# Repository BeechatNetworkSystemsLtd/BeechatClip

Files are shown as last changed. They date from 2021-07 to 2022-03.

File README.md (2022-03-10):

# Beechat Clip
## _The clip-on hardware for the Beechat Network_

BNSLTD

General
-------------------

This product is a plug-and-play RF module that operates with the Digi XBee SMT line. This unit works with all XBee SMT Pad modules, standard and Pro version. Design consists of an XBee® SX 868 module and USB-to-UART converter that allows users to simply plug the module into their smartphone over USB-C cable.

Additional on-board LED indication for TX/RX data, RSSI level and power (5V) in FT231XQ-R version. Reset tactile button allows rebooting the RF module when needed.  

Repository Contents
-------------------

* **/Hardware** - All Eagle design files (.brd, .sch)
* **/Production** - Test bed files and production panel files

Images
-------------------
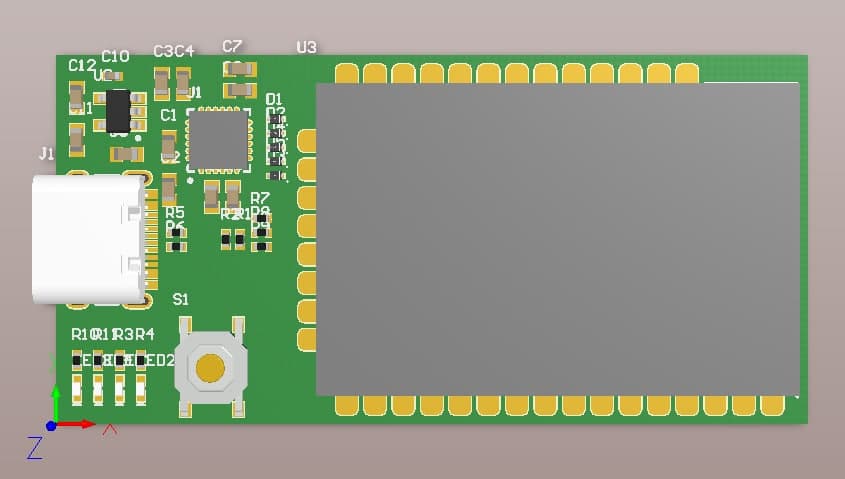
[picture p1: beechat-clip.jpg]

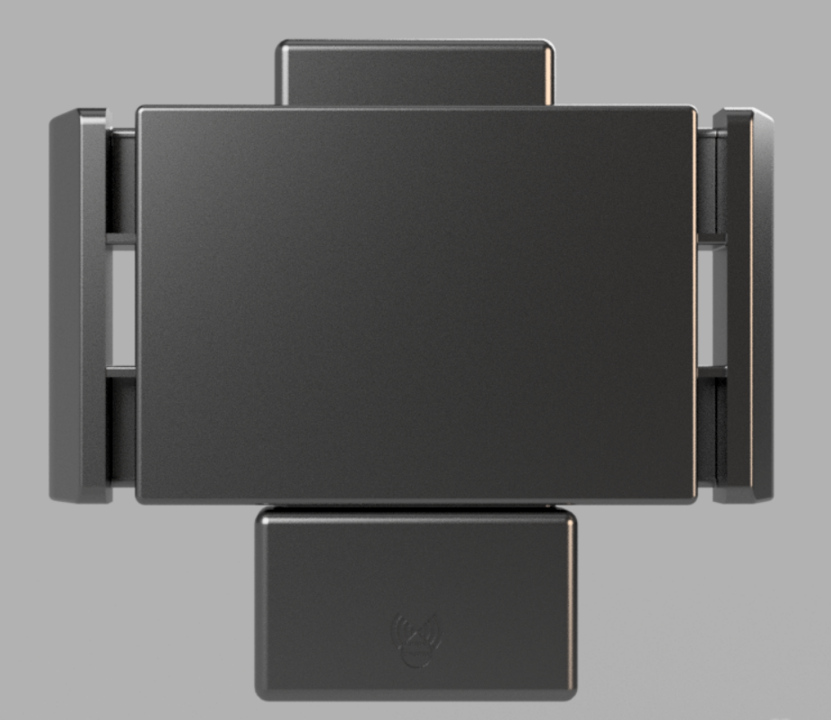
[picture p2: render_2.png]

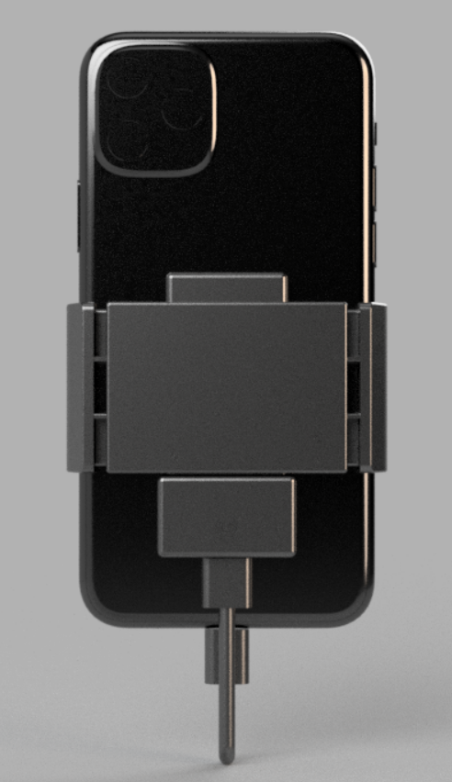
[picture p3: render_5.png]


Features
-------------------

* **Dimensions:** 26 x 53 mm
* **USB - UART bridge:** FT231XQ-R or XR21V1410
* **RF module:** XB8X-DMUS-001 or XBP9X-DMUS-001 or another XBee SX module
* **Input voltage:** 5V (USB)
* **Logic of UART signal:** 3.3V

Repository Contents
-------------------

/FT231XQ-R version:
* /Step 1 - PCB Manufacturing  (Gerber files, NC Drill, PCB specs)
* /Step 2 - Board Assembly (Pick & Place, Assembly drawing, 3DPDF, BOM)
* /Step 3 - 3D (3DPDF, STEP 3D)
* /Step 4 - Schematic (PDF schematic)
* /Step 5 - Source Files (source design in Altium Designer)

/XR21V1410 version:
* /Step 1 - PCB Manufacturing  (Gerber files, NC Drill, PCB specs)
* /Step 2 - Board Assembly (Pick & Place, Assembly drawing, 3DPDF, BOM)
* /Step 3 - 3D (3DPDF, STEP 3D)
* /Step 4 - Schematic (PDF schematic)
* /Step 5 - Source Files (source design in Altium Designer)

Product Versions
-------------------

REV1.0 - first design revision

License Information
-------------------
The hardware is released under [Creative Commons ShareAlike 4.0 International](https://creativecommons.org/licenses/by-sa/4.0/).
All other trademarks, service marks and company names are the property of their respective owners.

Distributed as-is; no warranty is given.

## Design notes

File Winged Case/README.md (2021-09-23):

# Beechat Clip Enclosure

BNSLTD

General
-------------------
This folder contains the files for the enclosure of the Beechat Clip.  

Bill of Materials
-------------------
 Sr No | Part name | Quantity | Material | Link/description |
| ------ | ------ | ------ | ------ | ------ |
|1 | Case top | 1 | PC
|2 | Case middle | 1 | PC
|3 | Case left | 1 | PC
|4 | Case right | 1 | PC
|5 | Spring | 2 | Spring steel | Wire dia- 0.5mm,  free length -11 mm, OD- 5mm, number of active coils =5
|6 | M1.6 screw 4mm | 2 |
|7 | M1.6 screw 6mm | 2 | 
|8 | Type C cable | 1 | 

REV1.0 - first design revision

License Information
-------------------
The hardware is released under [Creative Commons ShareAlike 4.0 International](https://creativecommons.org/licenses/by-sa/4.0/).

Distributed as-is; no warranty is given.

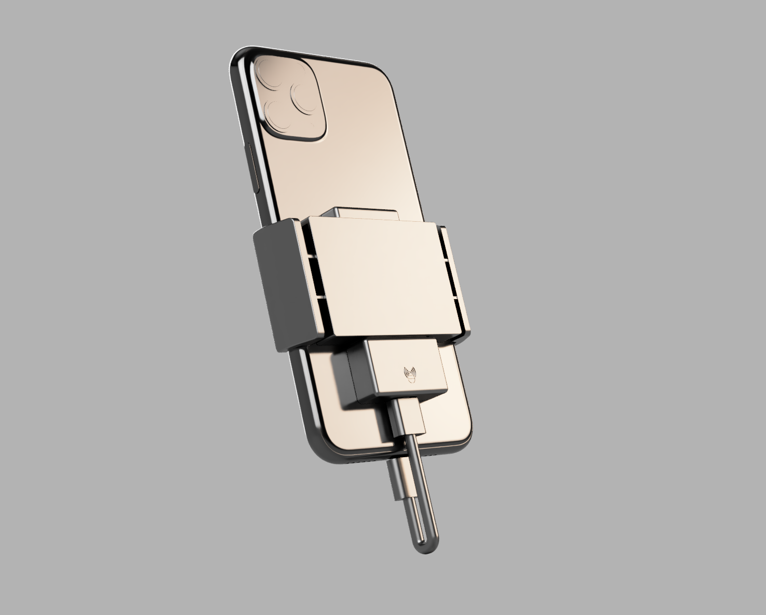
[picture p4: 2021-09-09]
render_1.PNG

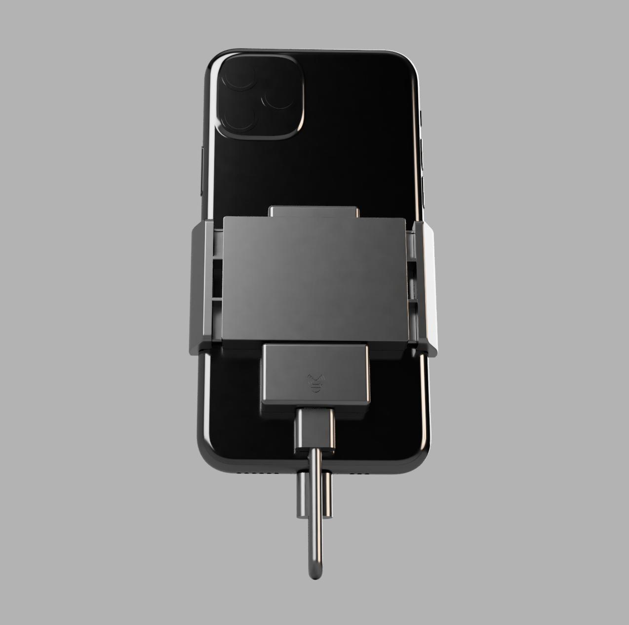
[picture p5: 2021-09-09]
Winged Case/Beechat clip render 4.PNG

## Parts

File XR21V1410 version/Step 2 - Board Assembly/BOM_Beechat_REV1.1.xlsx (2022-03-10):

 |  |  | Beechat, REV1.1 BOM file
 |  |  |  | Status: Checked
Disignator | Quantity | Value | Manufacturer Part Number | Description | Footprint | Supplier code
C1, C9 | 2 | 4.7uF | LMK107BJ475KA-T | CAP CER 4.7UF 10V X5R 0603 | CAP0603 | C1705
C2, C4, C6, C10 | 4 | 100nF | GRM155R71H104KE14D | CAP CER 0.1UF 50V X7R 0402 | CAP0402 | C105883
C3, C5, C7 | 3 | 10uF | LMK107BJ106MALTD | CAP CER 10UF 10V X5R 0603 | CAP0603 | C85713
C8 | 1 | 10nF | GCM155R71H103KA55D | CAP CER 10000PF 50V X7R 0402 | CAP0402 | C91601
D1, D2, D3, D4, D5 | 5 | - | ESD9B5.0ST5G | TVS DIODE 5V SOD923 | SOD-923 | C434878
J1 | 1 | - | USB4105-GF-A | USB SHIELDED I/O RECP TYPE C | SMD | C319148
LED1 | 1 | Green | APHHS1005CGCK | LED GREEN CLEAR CHIP SMD | LED0402 | C434446
LED2 | 1 | Red | APHHS1005LSECK/J3-PF | LED RED CLEAR 2SMD | LED0402 | C71911
R1, R2 | 2 | 22R | RC0402FR-0722RL | RES SMD 22 OHM 1% 1/16W 0402 | RES0402 | C114765
R3, R4 | 2 | 5.1K | RC0402FR-075K1L | RES SMD 5.1K OHM 1% 1/16W 0402 | RES0402 | C105872
R5, R6 | 2 | 4.7K | RC0402FR-074K7L | RES SMD 4.7K OHM 1% 1/16W 0402 | RES0402 | C105871
R7 | 1 | 330R | RC0402FR-07330RL | RES SMD 330 OHM 1% 1/16W 0402 | RES0402 | C105875
R8 | 1 | 1K | RT0402FRE071KL | RES SMD 1K OHM 1% 1/16W 0402 | RES0402 | C106235
S1 | 1 | - | 8-1437565-1 | SWITCH TACTILE SPST-NO 0.02A 15V | SMD | C318884
U1 | 1 | - | XR21V1410IL16-F | IC UART FIFO USB SGL 16QFN | QFN-16 | 1016-1300-ND
U2 | 1 | 3.3V | LDS3985M33R | IC REG LINEAR 3.3V 300MA SOT23-5 | SOT23-5 | C167141
U3 | 1 | - | XBP9X-DMUS-001 | RX TXRX MOD ISM < 1GHZ U.FL SMD | SMD | XBP9X-DMUS-001
TH = Through Hole
NF = Not fitted

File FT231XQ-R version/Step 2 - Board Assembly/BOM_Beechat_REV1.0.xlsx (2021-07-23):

 |  |  | Beechat, REV1.0 BOM file
 |  |  |  | Status: Checked
Disignator | Quantity | Value | Manufacturer Part Number | Description | Footprint | Note | PCBGOGO Supplier Alternative (LCSC)
C1, C7, C9 | 3 | 10uF | LMK107BJ106MALTD | CAP CER 10UF 10V X5R 0603 | CAP0603 | Can be replaced with alternative | C85713
C2, C8 | 2 | 47pF | C0402C470K5GACTU | CAP CER 47PF 50V C0G/NP0 0402 | CAP0402 | Can be replaced with alternative | C60137
C3, C11 | 2 | 4.7uF | LMK107BJ475KA-T | CAP CER 4.7UF 10V X5R 0603 | CAP0603 | Can be replaced with alternative | C1705
C4, C5, C6, C12, C13, C14 | 6 | 100nF | GRM155R71H104KE14D | CAP CER 0.1UF 50V X7R 0402 | CAP0402 | Can be replaced with alternative | C105883
C10 | 1 | 10nF | GCM155R71H103KA55D | CAP CER 10000PF 50V X7R 0402 | CAP0402 | Can be replaced with alternative | NOT FITTED
D1, D2, D3, D4, D5 | 5 | 5V | ESD9B5.0ST5G | TVS DIODE 5V SOD923 | SOD-923 | Can be replaced with alternative | C434878
J1 | 1 | - | USB4105-GF-A | USB SHIELDED I/O RECP TYPE C | TH | Can be replaced with alternative | C319148
LED1, LED3 | 2 | Green | APHHS1005CGCK | LED GREEN CLEAR CHIP SMD | LED0402 | Can be replaced with alternative | C434446
LED2, LED4 | 2 | Red | APHHS1005LSECK/J3-PF | LED RED CLEAR 2SMD | LED0402 | Can be replaced with alternative | C71911
R3, R4, R11 | 3 | 1K | RT0402FRE071KL | RES SMD 1K OHM 1% 1/16W 0402 | RES0402 | Can be replaced with alternative | C106235
R5, R6 | 2 | 22R | RC0402FR-0722RL | RES SMD 22 OHM 1% 1/16W 0402 | RES0402 | Can be replaced with alternative | C114765
R8, R9 | 2 | 5.1K | RC0402FR-075K1L | RES SMD 5.1K OHM 1% 1/16W 0402 | RES0402 | Can be replaced with alternative | C105872
R10 | 1 | 330R | RC0402FR-07330RL | RES SMD 330 OHM 1% 1/16W 0402 | RES0402 | Can be replaced with alternative | C105875
S1 | 1 | - | 8-1437565-1 | SWITCH TACTILE SPST-NO 0.02A 15V | SMD | Can be replaced with alternative | C318884
U1 | 1 | - | FT231XQ | IC USB SERIAL FULL UART 20QFN | QFN-20
U2 | 1 | 3.3V | LDS3985M33R | IC REG LINEAR 3.3V 300MA SOT23-5 | SOT23-5 | Can be replaced with alternative | C167141
U3 | 1 | - | XB8X-DMUS-001 | RX TXRX MOD ISM < 1GHZ U.FL SMD | SMD
TH = Through Hole
NF = Not fitted

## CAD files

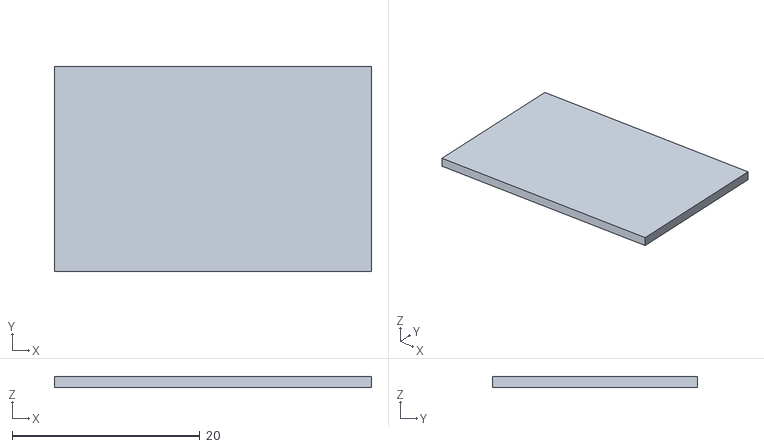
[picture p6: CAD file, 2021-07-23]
FT231XQ-R version/Step 3 - 3D/Beechat_PCB_REV1.0.stl
33.8 x 21.9 x 1.20

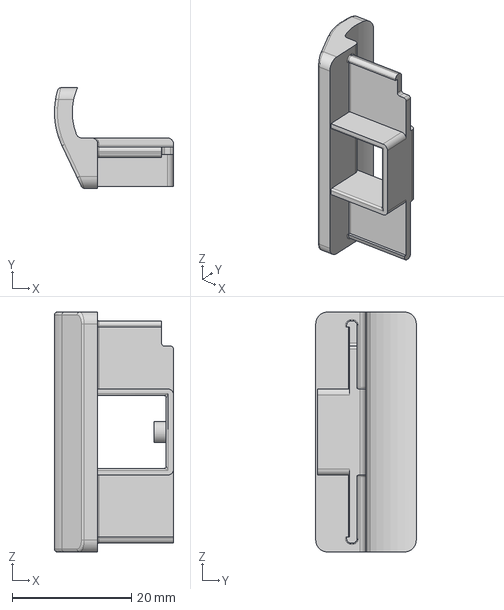
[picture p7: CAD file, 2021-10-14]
Step 6 - Enclosure case/parts/Case_right.step
20.0 x 16.9 x 40.3 mm

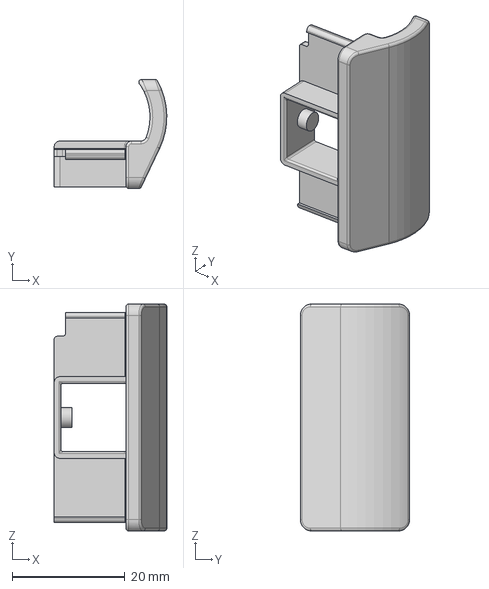
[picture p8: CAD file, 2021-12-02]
Winged Case/parts/Arm Model B .25cm/Case_Left-0.25CM.step
20.0 x 19.4 x 40.3 mm

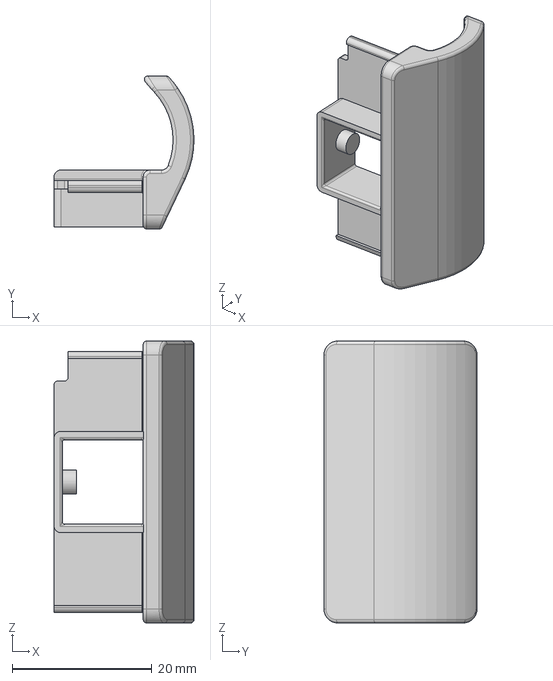
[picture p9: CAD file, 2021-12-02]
Winged Case/parts/Arm Model C .5cm/Case_Left-0.5CM.step
20.0 x 21.9 x 40.3 mm

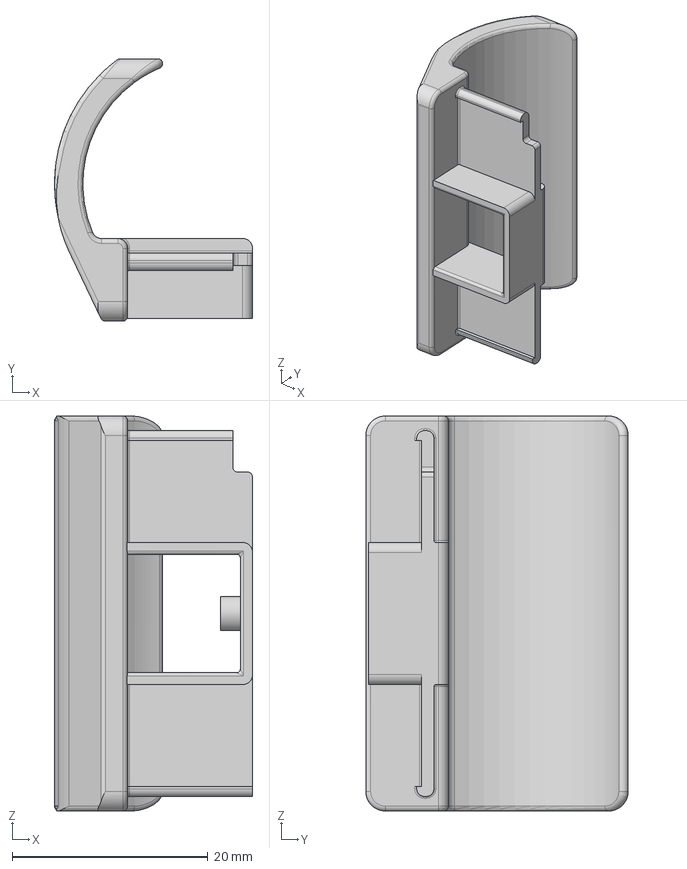
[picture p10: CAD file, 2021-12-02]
Winged Case/parts/Arm Model D 1cm/Case_Right-1CM.step
20.2 x 26.8 x 40.3 mm

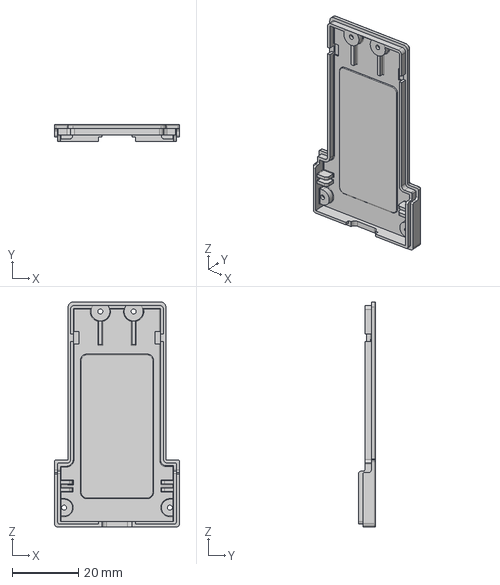
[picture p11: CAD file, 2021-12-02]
Winged Case/parts/Case_bottom.step
37.7 x 5.14 x 67.7 mm

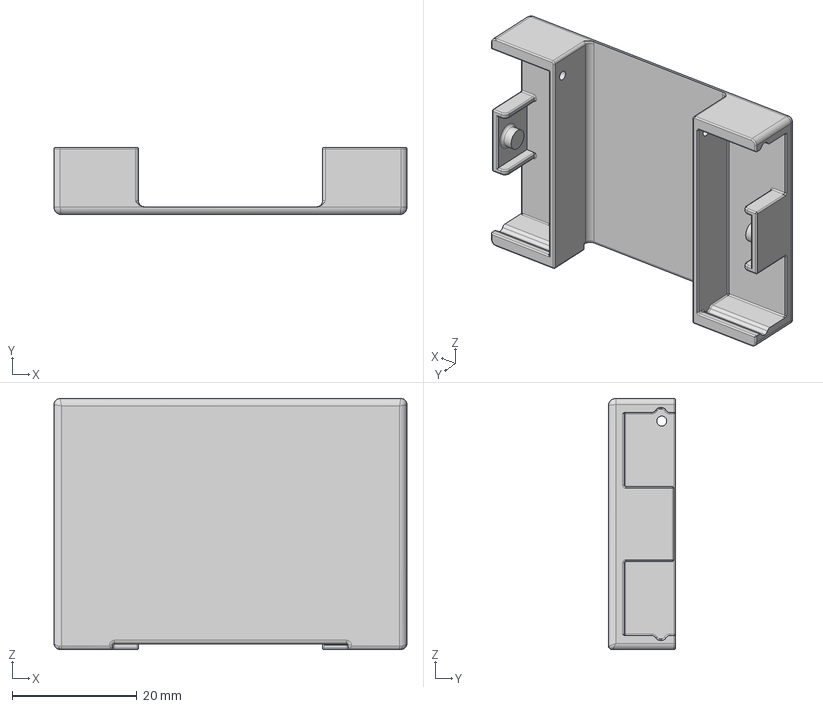
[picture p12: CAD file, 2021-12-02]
Winged Case/parts/Case_middle.step
56.7 x 10.8 x 40.3 mm

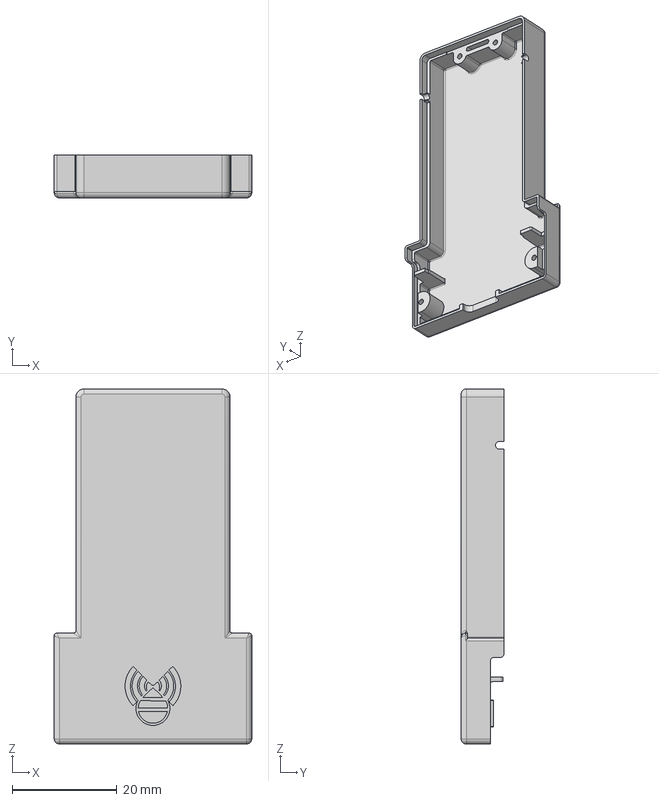
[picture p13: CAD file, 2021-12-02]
Winged Case/parts/Case_top.step
37.7 x 8.18 x 67.7 mm

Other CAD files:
Winged Case/parts/Arm Model A 0mm/Case_Right-0CM.step
Step 6 - Enclosure case/parts/Case_left.step
Winged Case/parts/Arm Model A 0mm/Case_Left-0CM.step
Winged Case/parts/Arm Model B .25cm/Case_Right-0.25CM.step
Winged Case/parts/Arm Model C .5cm/Case_Right-0.5CM.step
Winged Case/parts/Arm Model D 1cm/Case_Left-1CM.step

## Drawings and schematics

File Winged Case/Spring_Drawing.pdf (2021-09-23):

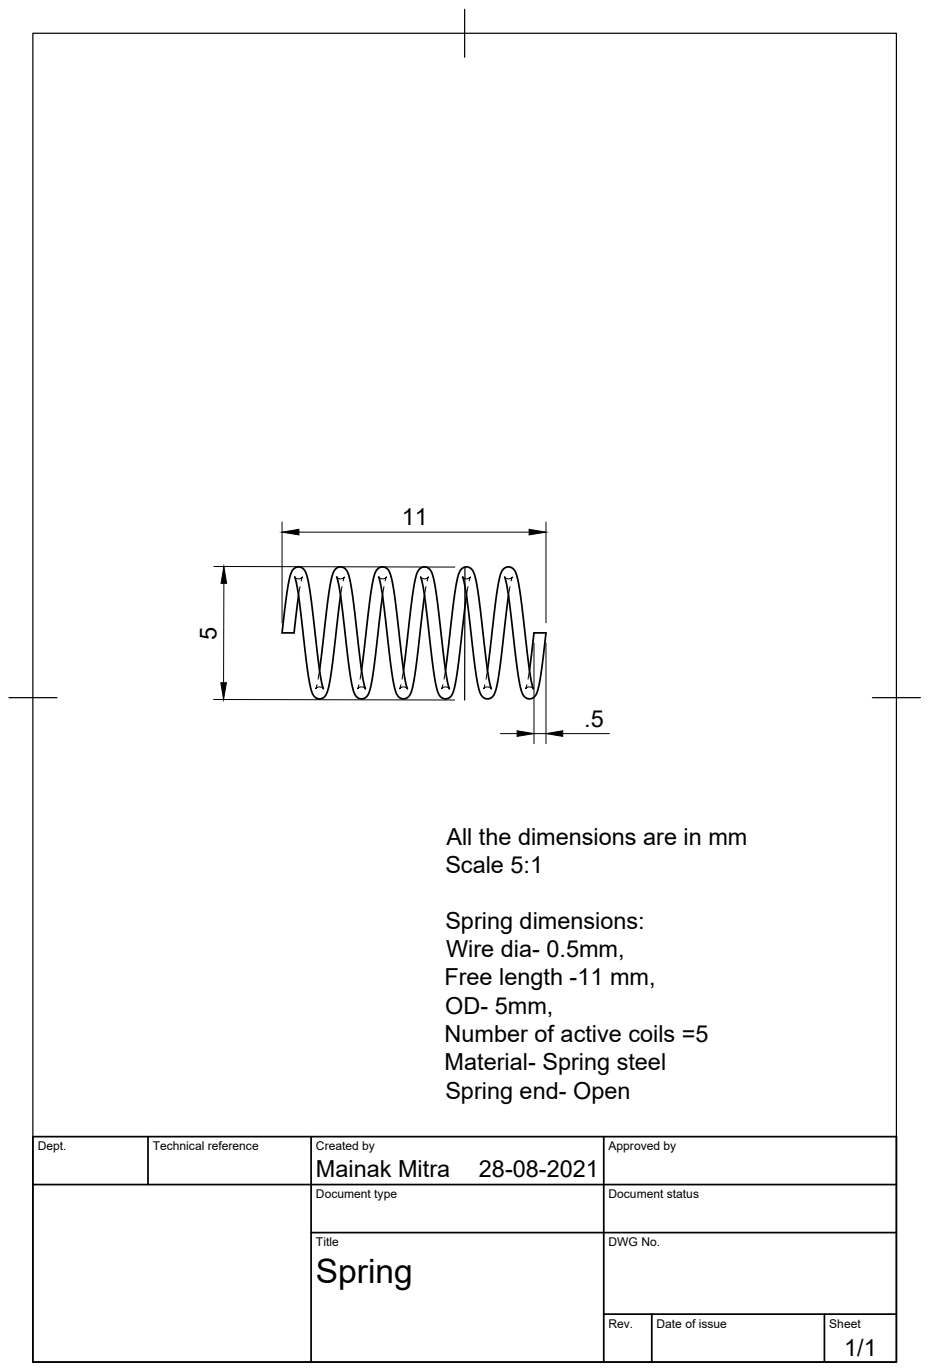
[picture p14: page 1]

All the dimensions are in mm
Scale 5:1

Spring dimensions:
Wire dia- 0.5mm,
Free length -11 mm,
Number of active coils =5
Material- Spring steel
Spring end- Open

Dept. | Technical reference | Created by Mainak Mitra 28-08-2021 | Approved by

Document type | Document status

Title Spring | DWG No.

Rev. | Date of issue | Sheet 1/1

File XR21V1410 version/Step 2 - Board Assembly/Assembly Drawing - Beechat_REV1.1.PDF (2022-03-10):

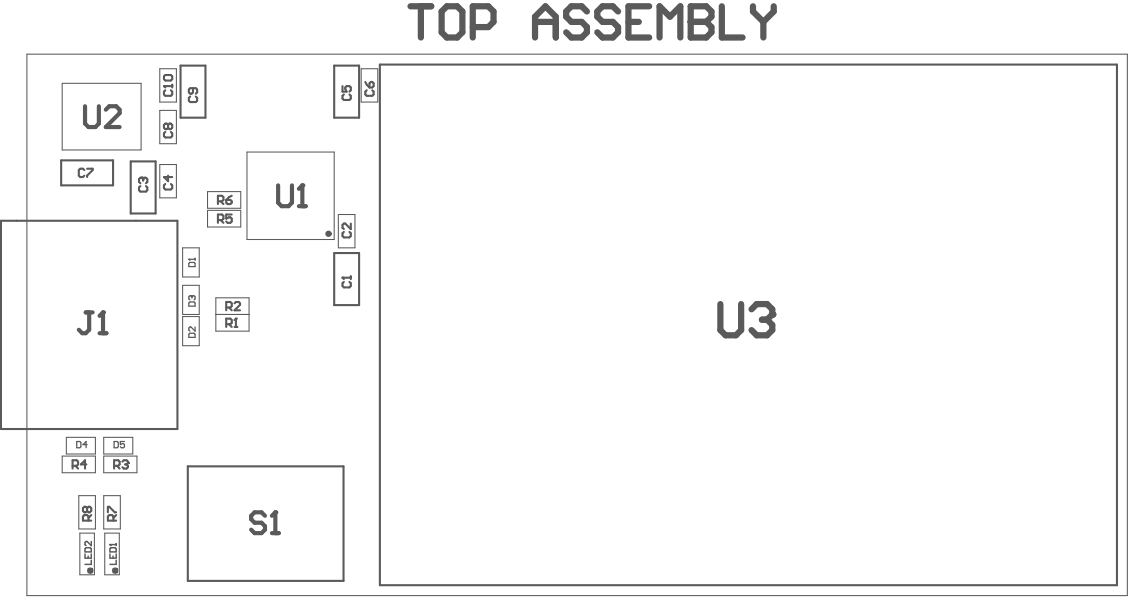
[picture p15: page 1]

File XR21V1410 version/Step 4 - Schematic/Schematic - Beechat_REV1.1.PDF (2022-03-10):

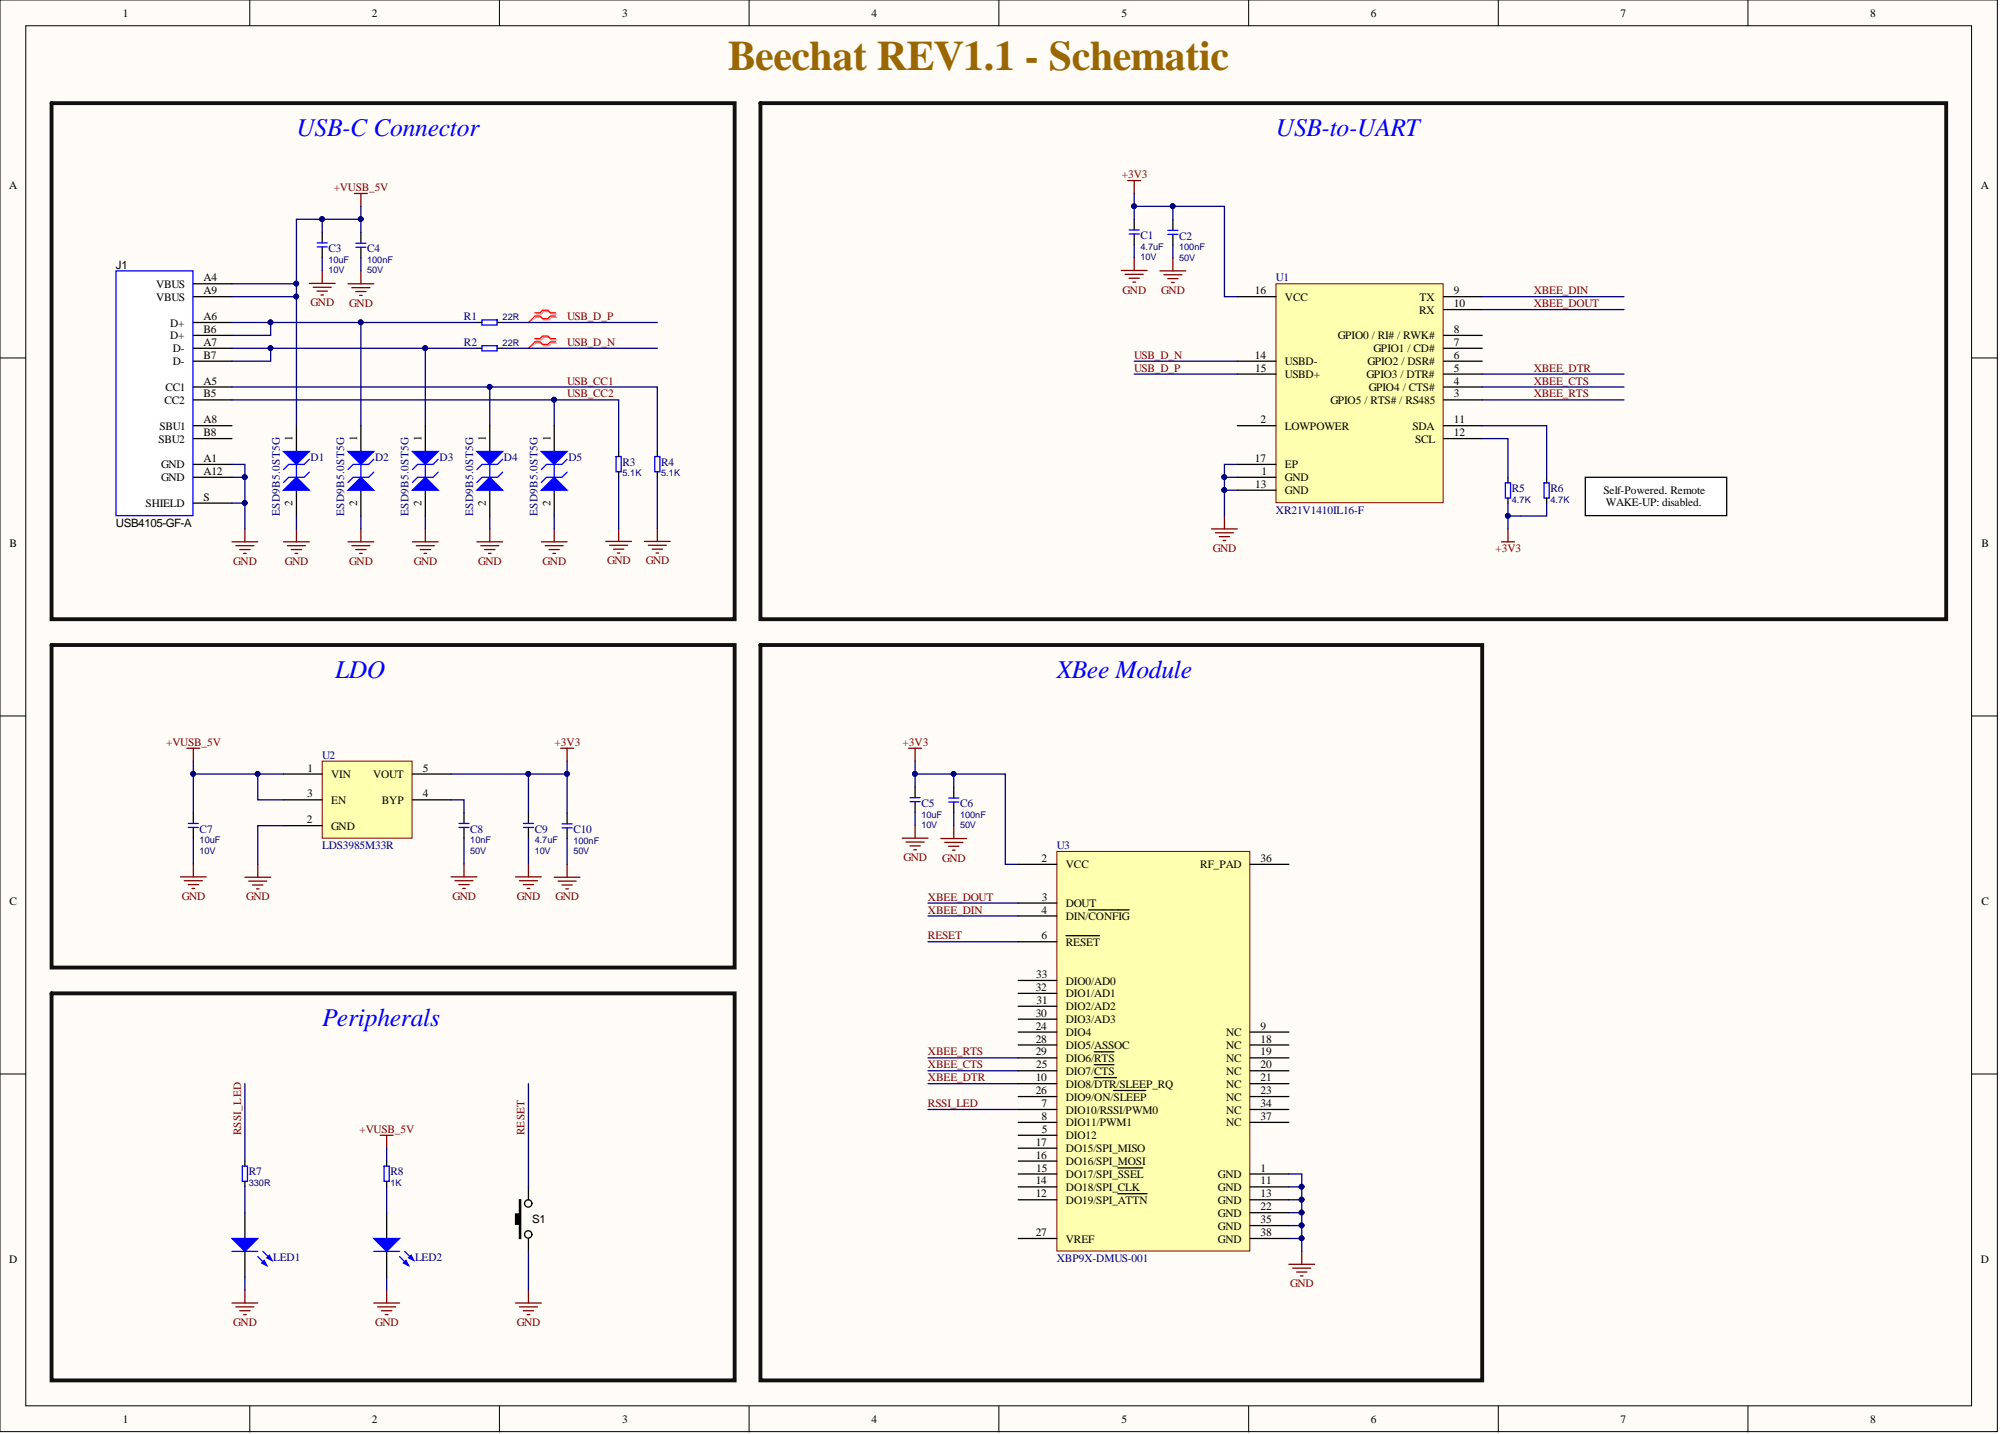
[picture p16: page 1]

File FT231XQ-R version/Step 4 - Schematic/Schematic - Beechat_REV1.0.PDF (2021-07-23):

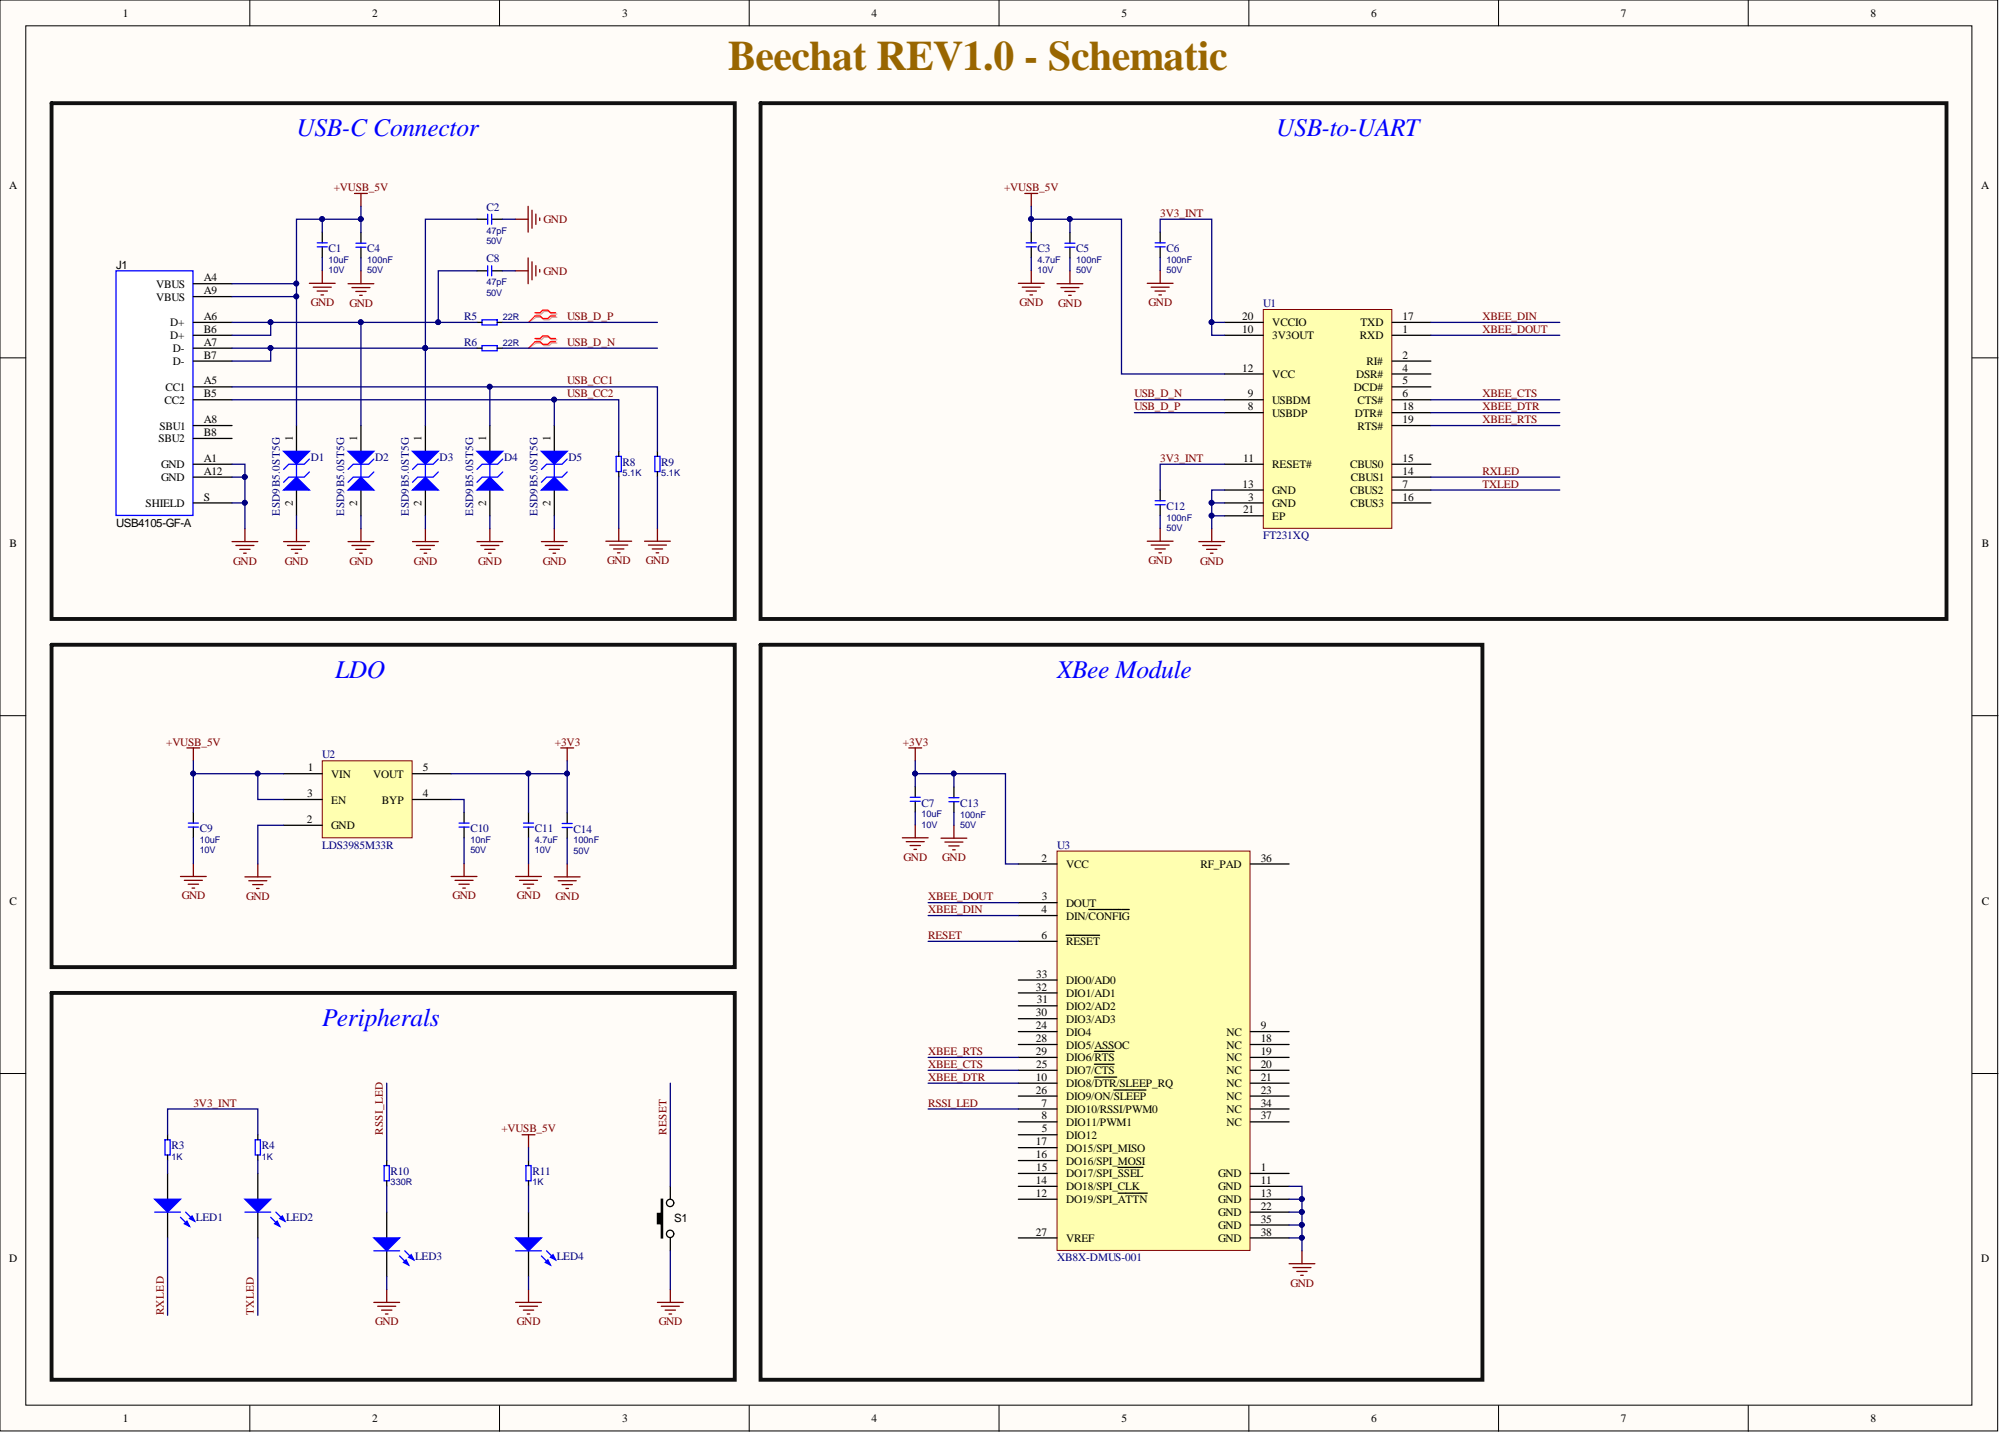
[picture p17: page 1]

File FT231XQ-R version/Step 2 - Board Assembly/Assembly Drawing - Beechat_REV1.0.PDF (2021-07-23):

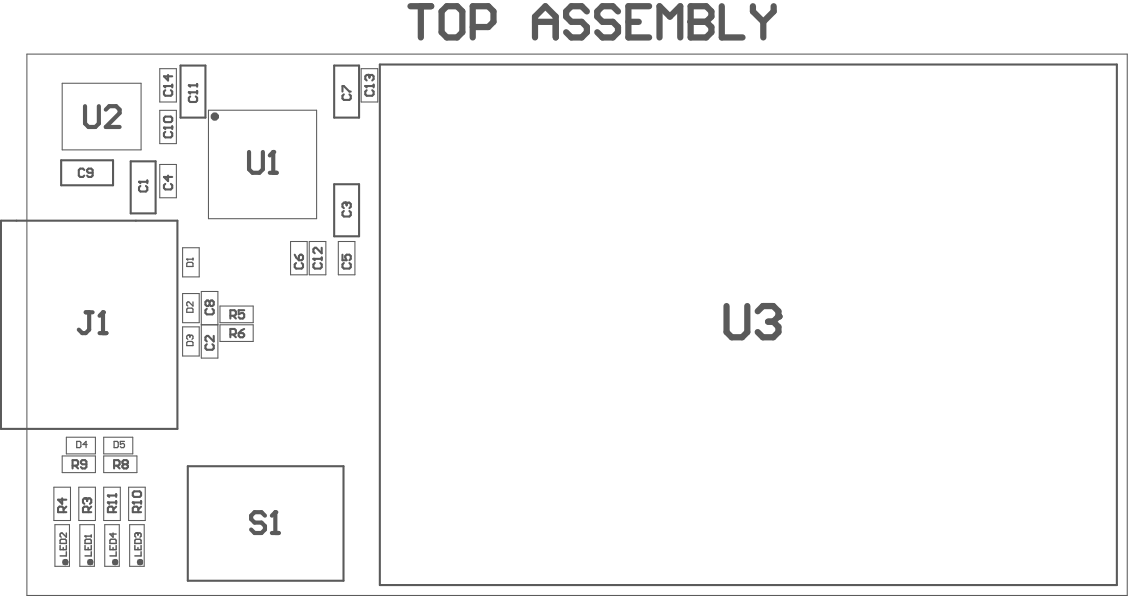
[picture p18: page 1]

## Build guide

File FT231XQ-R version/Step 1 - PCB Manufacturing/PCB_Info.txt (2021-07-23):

General info:
- PCB Size 53x26mm
- FR4-1.0mm
- Minimum track: 0.2mm / Minimum gap: 0.2mm
- 2 layers 
- HASL
- 1oz copper thickness
- green solder mask, white silkscreen

– Used VIAs:
1) Through hole VIA: 0.65mm (pad) / 0.3mm (drill)
2) Through hole VIA: 0.9mm (pad) / 0.5mm (drill)

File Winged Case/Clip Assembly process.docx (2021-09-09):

Step 1 - Place the “case top” upside down

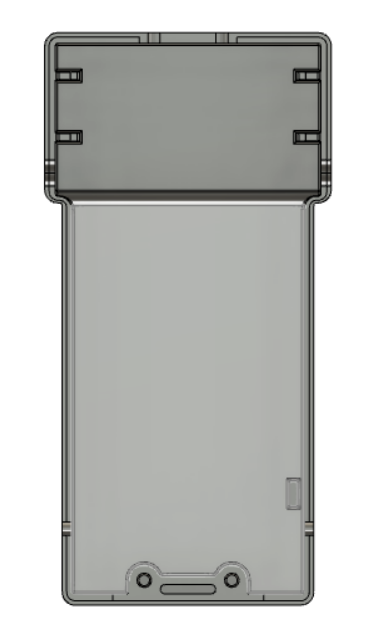
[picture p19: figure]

Step 2 -Stick the antenna on the case top using yellow tape

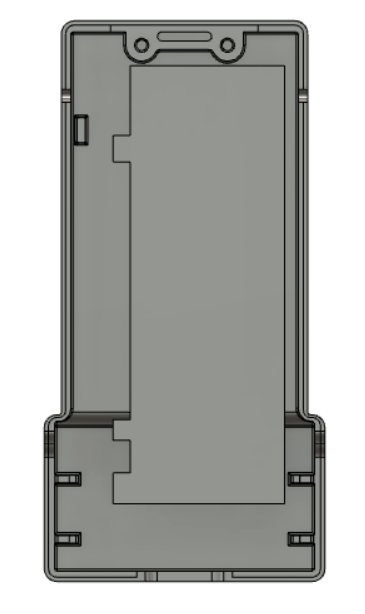
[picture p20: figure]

Step 4 - Place the “Case top” on top of the “Clip middle” part

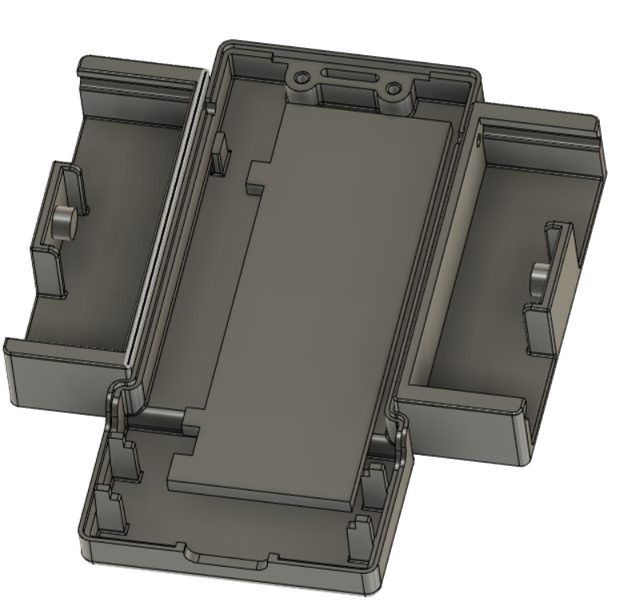
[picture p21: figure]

Step 5 - Fix the case top and the Clip using M1.6 8mm screws and nuts as shown in the image below.

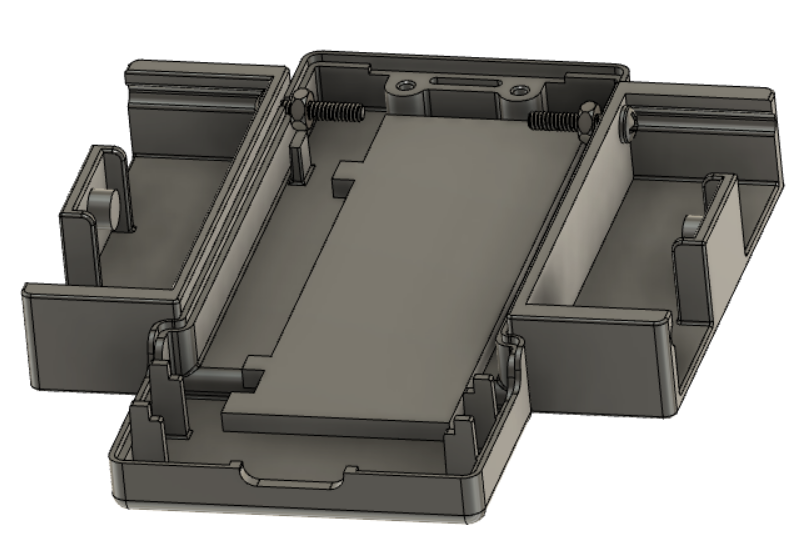
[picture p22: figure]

Step 7 -Place the PCB on top and connect the antenna UFL connector to the PCB

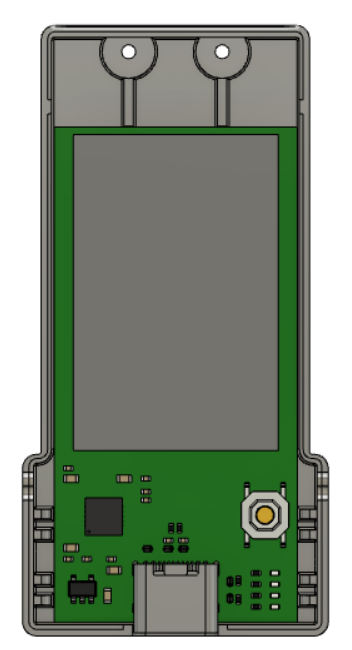
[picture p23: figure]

Step 8 -Put the Case bottom part and fix it with two M1.6 screws.

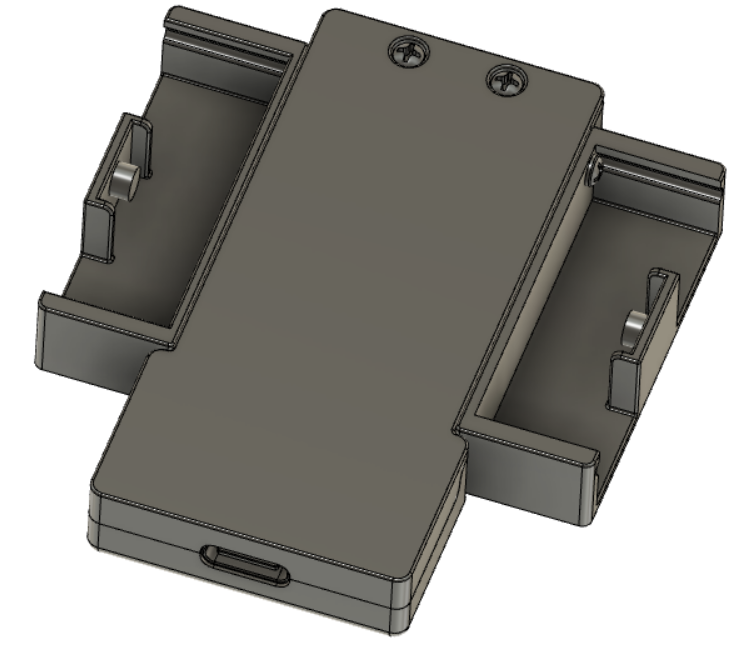
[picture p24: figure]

Step 9 - Push the Clip left and right part so that it snaps into the groove as shown in the image below.

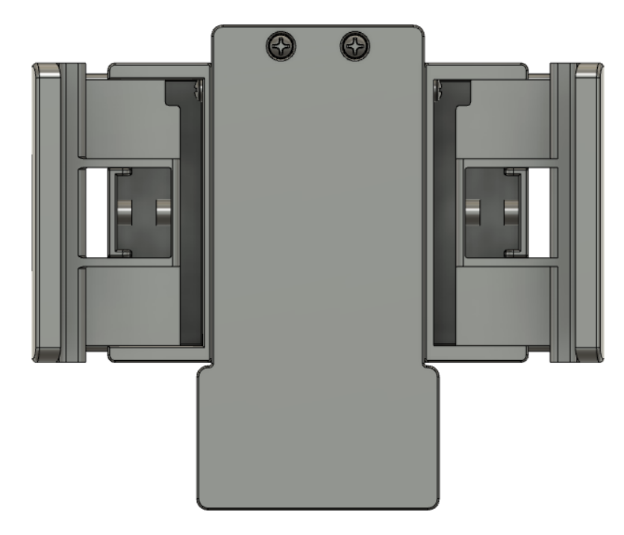
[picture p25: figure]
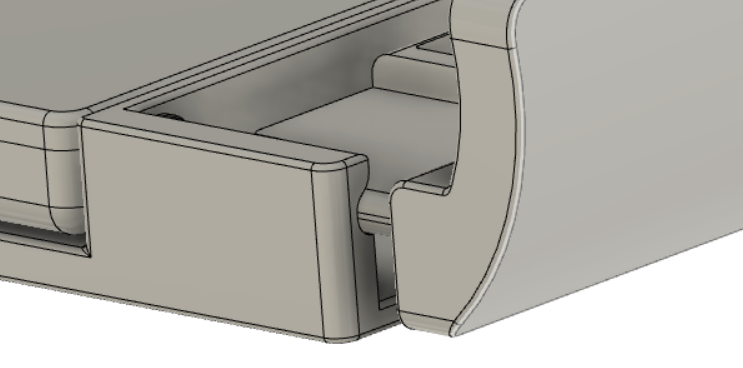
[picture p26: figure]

Step 10 -Push the springs inside. The cylindrical structure should be inside the spring.

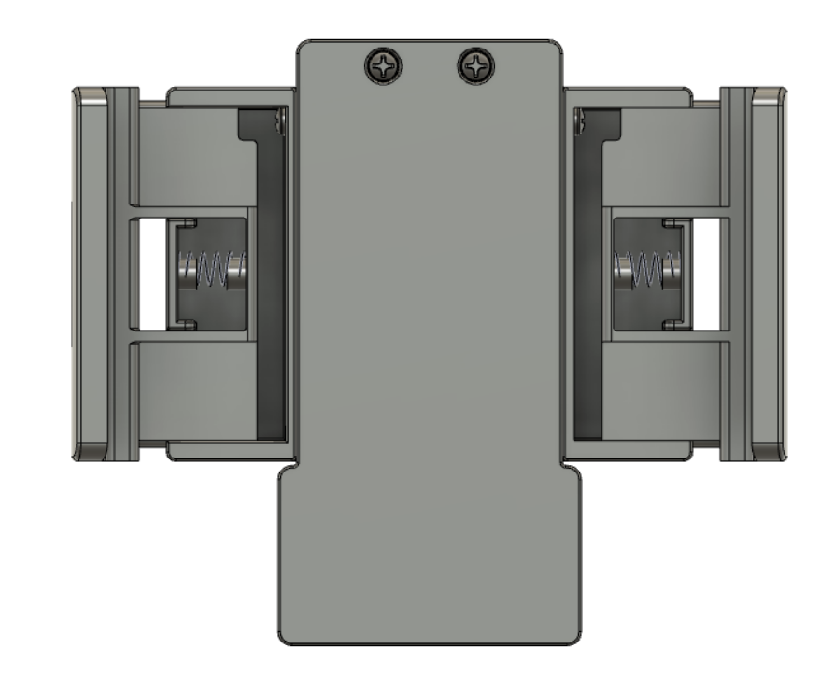
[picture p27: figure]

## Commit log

2021-09-23 Deleted BOM.xlsx
    BOM has been added to the README.md file
    [Beechat Case BOM.xlsx]
2021-12-02 Added different arm lengths
    0MM (short), 0.25 CM, 0.5 CM, 1 CM
    [Case_Left-0.25CM.step, Case_Left-0.5CM.step, Case_Left-0CM.step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]
2022-03-10 Added XR21V1410 version
    There has been a severe shortage of FTDI FT231XQ-R chip. Prices have risen from less than 5 USD to over 50 USD per chip. This version is an alternative with a UART-USB bridge chip that is currently available in markets.
    [BOM_Beechat_REV1.0.xlsx, BOM_Beechat_REV1.1.xlsx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]
